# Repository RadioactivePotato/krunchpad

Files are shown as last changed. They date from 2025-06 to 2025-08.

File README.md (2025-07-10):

# krunchpad
A macropad powered by RP2040

# Images

| Schematic | PCB | 3D Preview | Case |
|:---:|:---:|:----:|:----:|
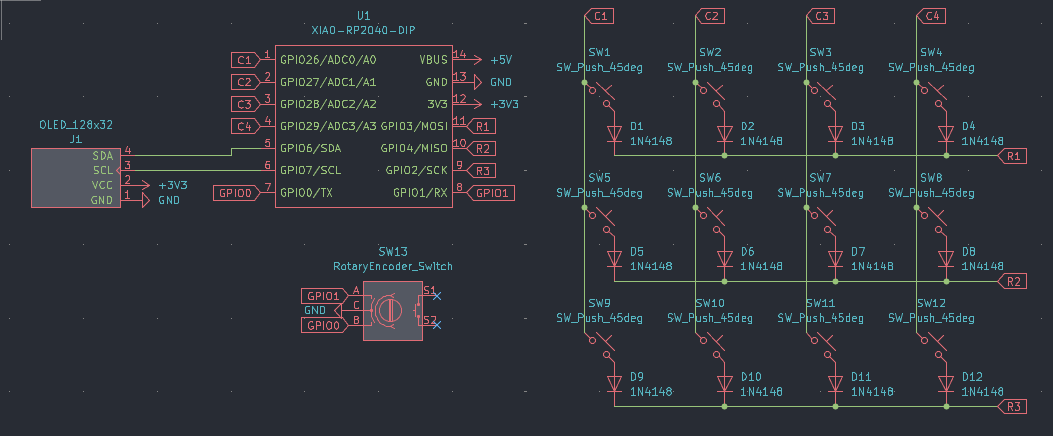
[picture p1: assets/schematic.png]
Schematic
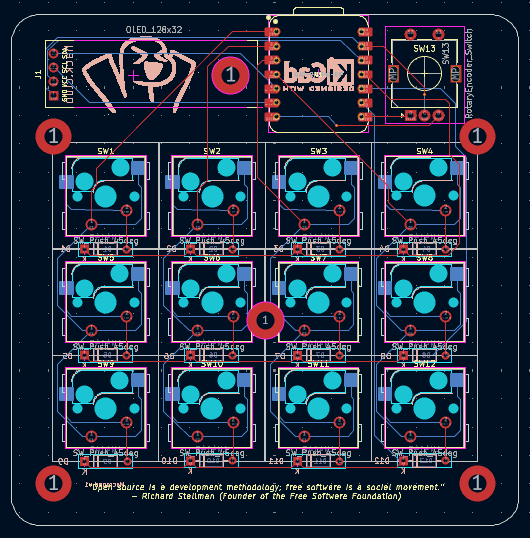
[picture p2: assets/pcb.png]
PCB
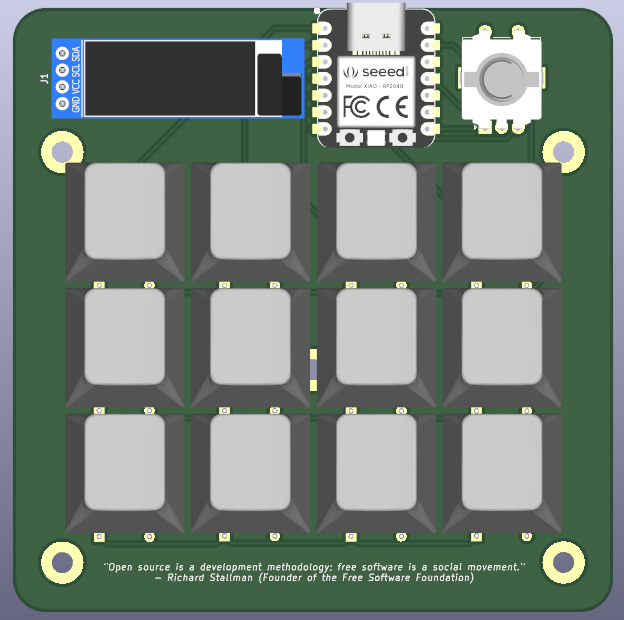
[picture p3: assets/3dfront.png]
3D-Front
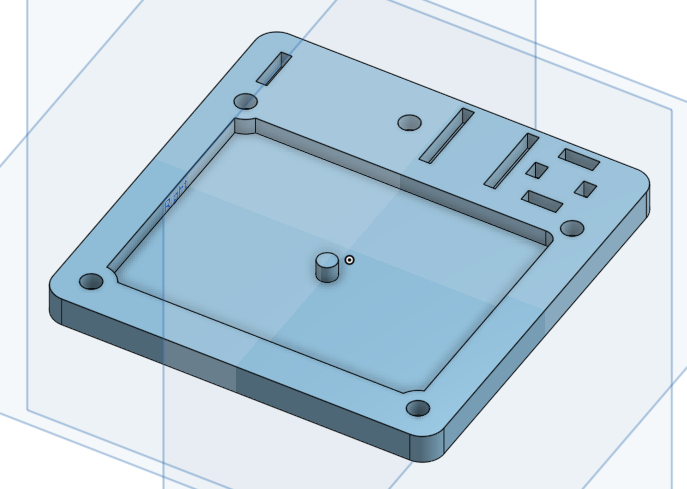
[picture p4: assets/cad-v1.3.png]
Baseplate
|  |  |  |  |
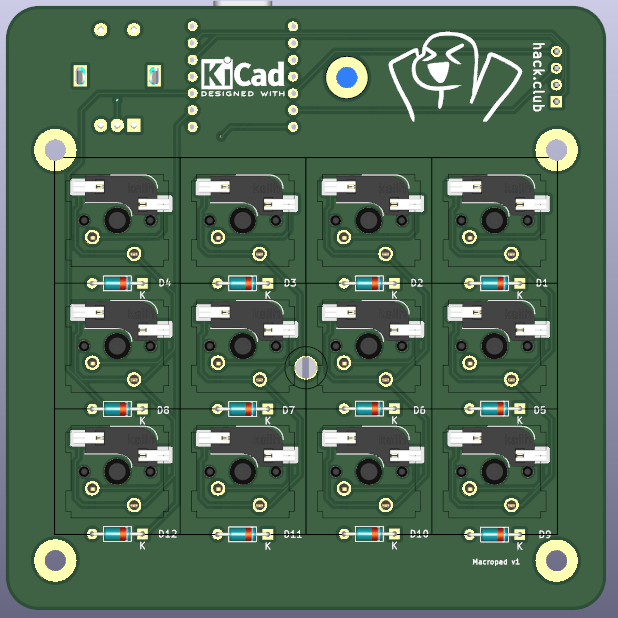
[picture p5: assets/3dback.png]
3D-Back
| | |  | |

# Case

| Layout | Layout | Layout |
| :----: | :----: | :----: |
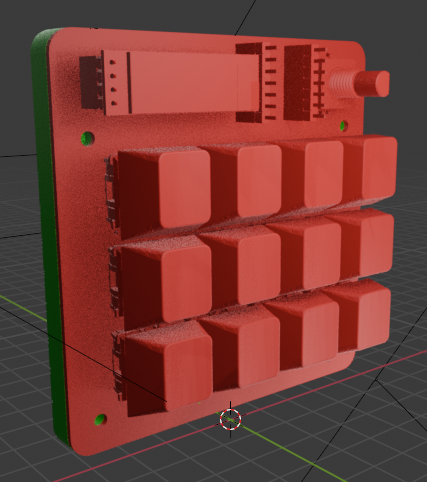
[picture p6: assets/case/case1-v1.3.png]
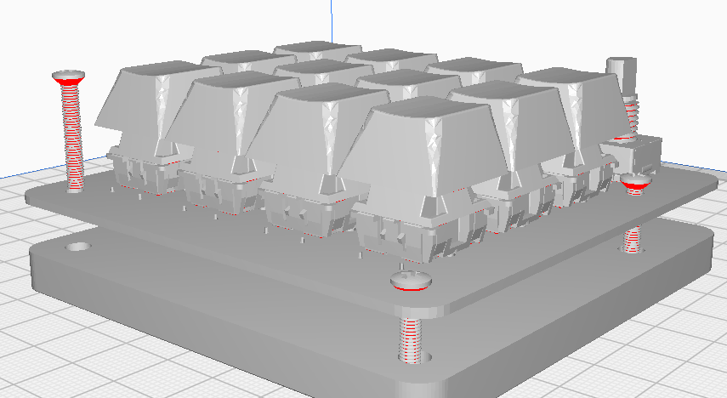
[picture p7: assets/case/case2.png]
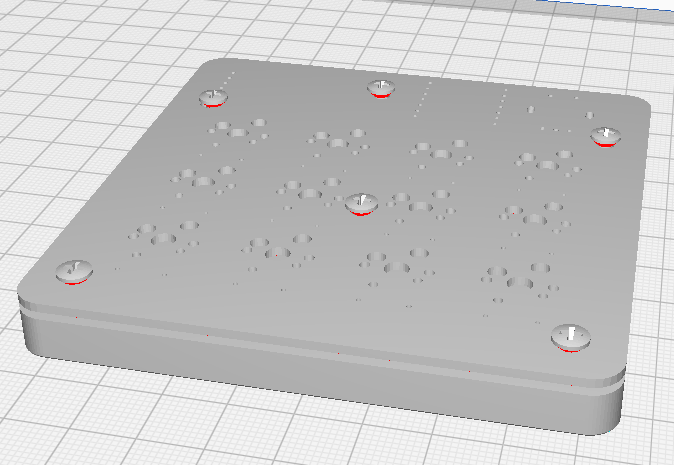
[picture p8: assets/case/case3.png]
|  |  |  |

# BOM
| Qty  | Item | Notes | Cost (USD)| URL |
|---|---|---|---|---|
| 1 | Seeed Studio XIAO RP2040 | Microcontroller | $4.68 | [URL](https://www.digikey.co.uk/en/products/detail/seeed-technology-co-ltd/102010428/14672129) |
| 12 | THT 1N4148 Diode (DO-35 Footprint) | For switch matrix | $0.41 | [URL](https://www.digikey.co.uk/en/products/detail/diotec-semiconductor/1N4148/13164514) |
| 12 | MX-Style Switches | Mechanical key switches | | |
| 1 | EC11 Rotary Encoder | Volume control | $1.87 | [URL](https://www.digikey.co.uk/en/products/detail/bourns-inc/PEC11R-4215K-S0012/4499639) |
| 1 | 0.91" OLED Display | | | |
| 12 | Keycaps | | | |
| 5 | M3x5mmx4mm Heatset Inserts (W*H) | For mounting | | |
| 6 | M3 Screws (5.6mm Max) | For case assembly | | |
|------|------------------------------------|---------------------------|-----------|---------|
| 1 | Soldering Iron + Solder | Tools | | |
| 1 | 3D Printed Case | Custom enclosure | | |
| 1 | PCB | | | |
|------|------------------------------------|---------------------------|-----------|---------|
| 2 | 2.54mm 4POS Header (Included) | OLED Mounting | | |
| 2 | 2.54mm 4POS Socket | OLED Mounting | $0.25 | [URL](https://www.digikey.co.uk/en/products/detail/adam-tech/RS1-04-G/9829303) |
| 2 | 2.54mm 7POS Header | MCU Mounting | $0.20 | [URL](https://www.digikey.co.uk/en/products/detail/adam-tech/PH1-07-UA/9830505) |
| 2 | 2.54mm 7POS Socket | MCU Mounting | $0.84 | [URL](https://www.digikey.co.uk/en/products/detail/adam-tech/RS1-07-G/9832045) |
| 12 | Kailh MX Hotswap Socket (Optional) | Hotswapping for switches  | $4.95 | [URL](https://www.digikey.co.uk/en/products/detail/adafruit-industries-llc/4958/13997772) |
|------|------------------------------------|---------------------------|-----------|---------|

# Cases
- V1

Simple base plate with slots for heatset inserts

- V1.1

Added holes for the PCB to sit flush with the case where there are THT componants

- V1.2

Added a support knob to support the PCB in the center of the case

- V1.3

Added slots for the socket for the MCU

Removed the curved corners for the holes

A badge of a Cerberus and a raccoon laughing together, with the text "HIGHWAY" and "HACK CLUB" beside them.

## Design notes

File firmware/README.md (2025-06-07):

### Features

#### 3×4 Key Matrix

* 12 customizable keys in 3 rows and 4 columns.
* Default keymap sends letters A–L.

#### Rotary Encoder

* EC11 rotary encoder connected to GPIO0 and GPIO1.
* Turns:

  * Clockwise > Volume Up
  * Counterclockwise > Volume Down

#### OLED Display

* Displays `"Hello World"` centered vertically on boot.
* OLED dims after 10 seconds of inactivity, turns off after 20 minutes (1200 seconds).

---

### Pins

| Function | GPIO Pins |
| --- | --- |
| Matrix Rows | GP3, GP4, GP2 |
| Matrix Columns | GP26, GP27, GP28, GP29 |
| Encoder A/B | GP1, GP0 |

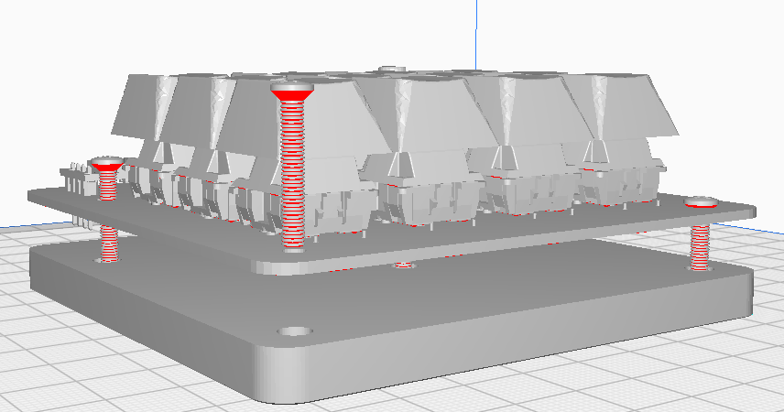
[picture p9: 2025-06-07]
assets/case/case1.png

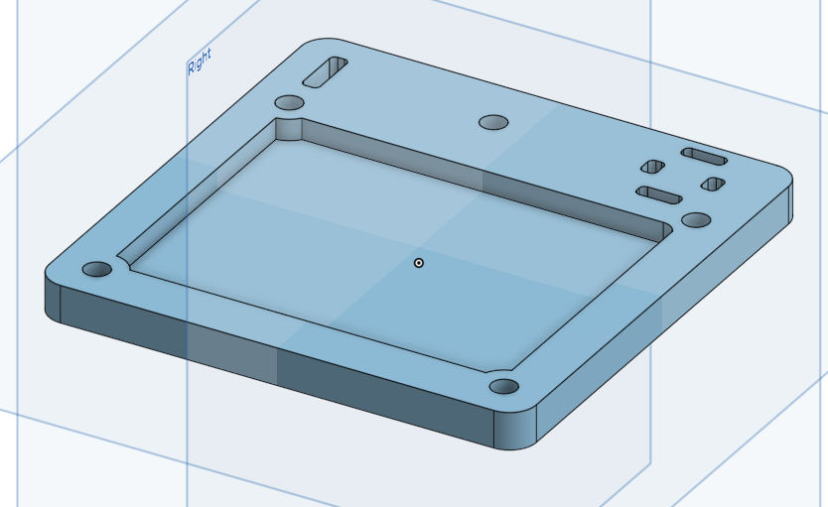
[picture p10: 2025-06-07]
assets/cad-v1.1.png

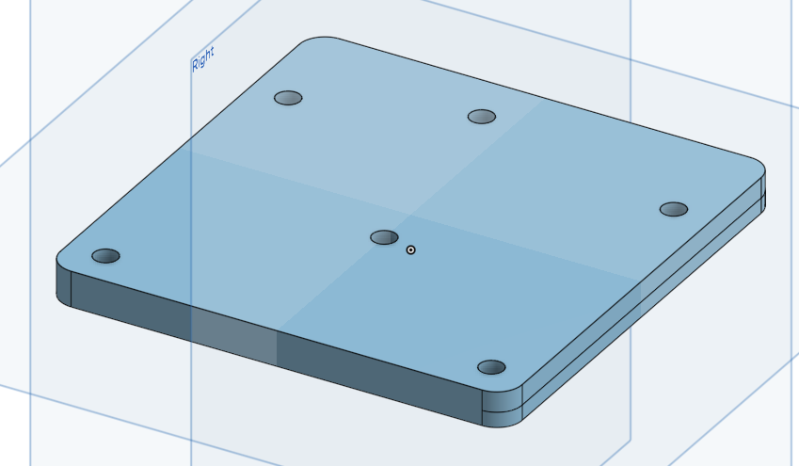
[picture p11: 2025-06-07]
assets/cad-v1.png

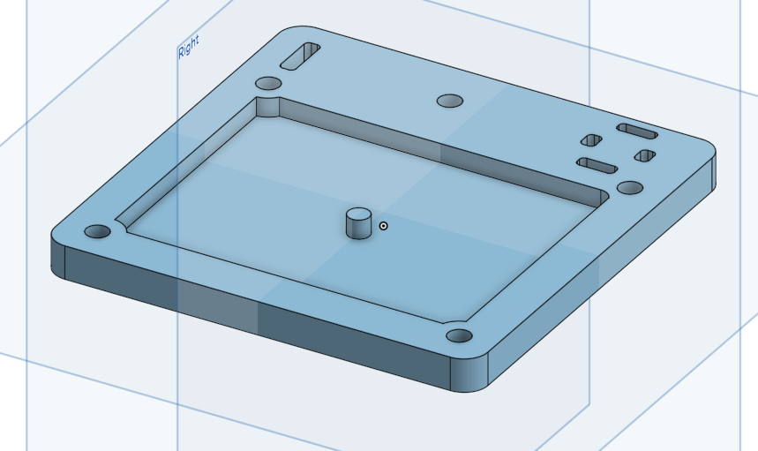
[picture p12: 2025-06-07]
assets/cad-v1.2.png

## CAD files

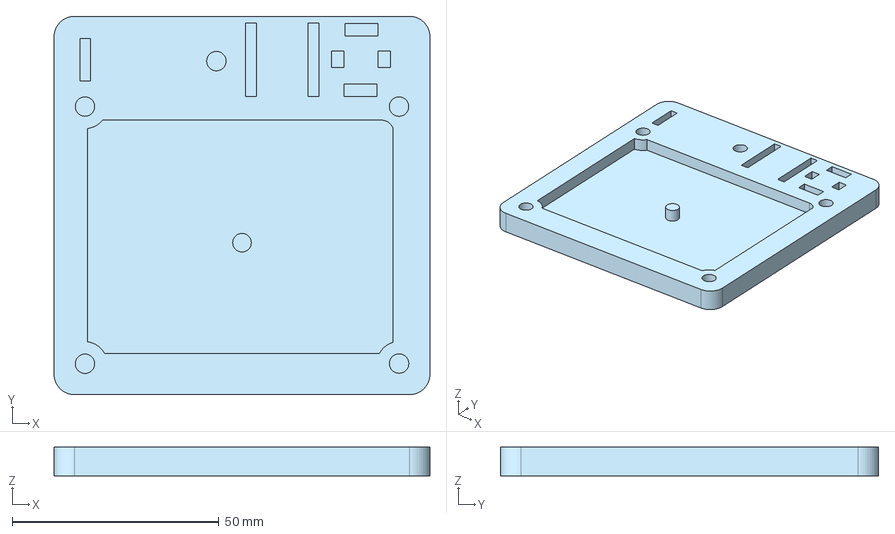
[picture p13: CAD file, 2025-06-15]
cad/v1.3-krunchpad-baseplate.step
91.0 x 91.6 x 7.00 mm

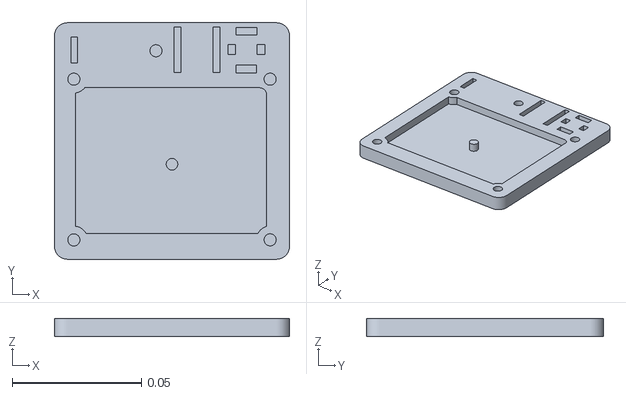
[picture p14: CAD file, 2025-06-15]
production/v1.3-krunchpad-baseplate.stl
0.091 x 0.0916 x 0.007

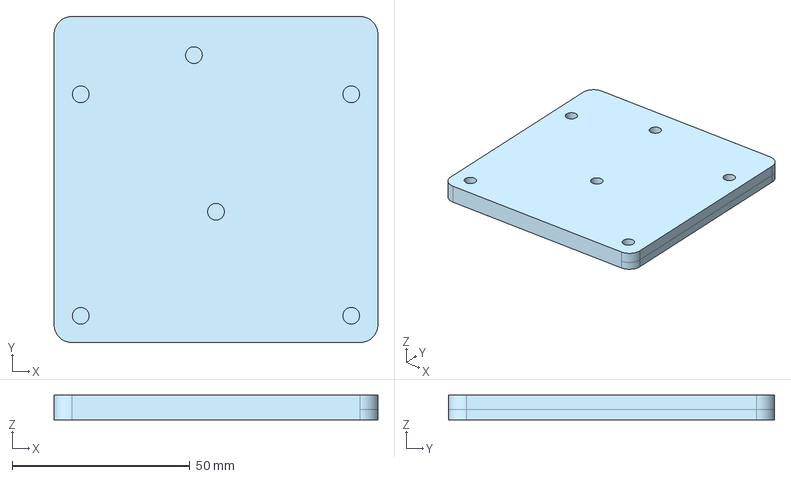
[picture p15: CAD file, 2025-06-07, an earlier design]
cad/v1-krunchpad-baseplate.step
91.0 x 91.6 x 7.00 mm

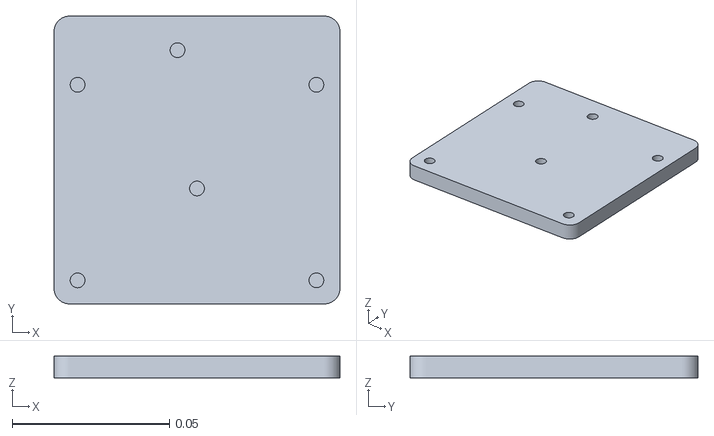
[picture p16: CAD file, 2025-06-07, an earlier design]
production/v1-krunchpad-baseplate.stl
0.091 x 0.0916 x 0.007

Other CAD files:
production/v1.2-krunch-baseplate.stl
cad/v1.1krunchpad-baseplate.step
cad/v1.2-krunchpad-baseplate.step
production/v1.1-krunchpad-baseplate.stl

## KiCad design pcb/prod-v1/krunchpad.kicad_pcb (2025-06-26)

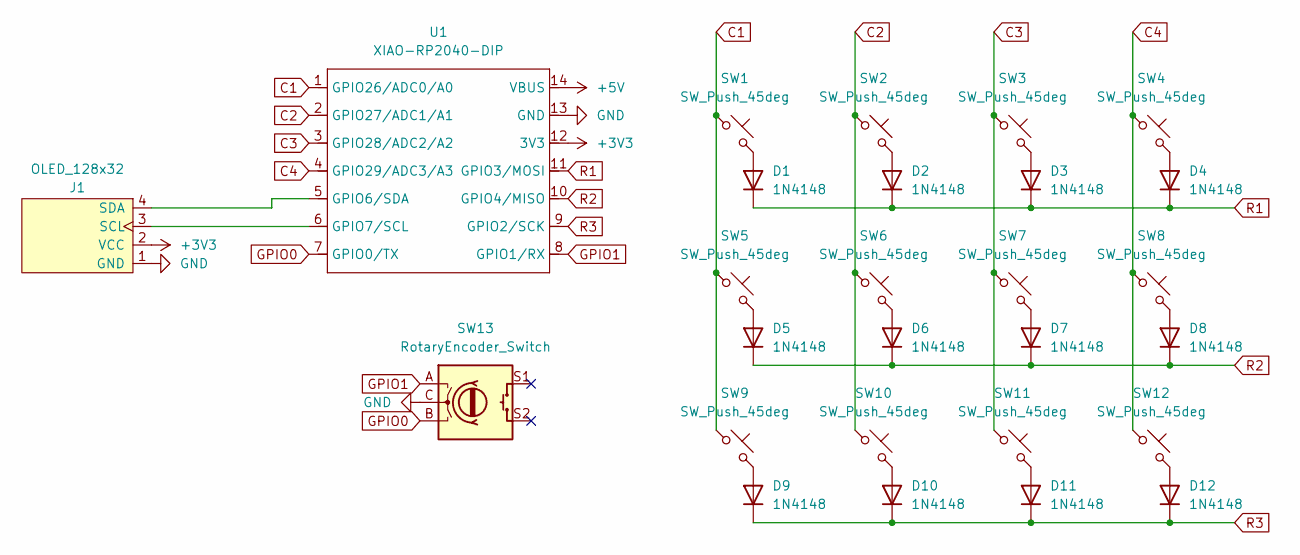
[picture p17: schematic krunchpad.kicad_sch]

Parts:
D1, D2, D3, D4, D5, D6, D7, D8, D9, D10, D11, D12: 1N4148; D_DO-35_SOD27_P7.62mm_Horizontal
J1: OLED_128x32; SSD1306-0.91-OLED-4pin-128x32
SW1, SW2, SW3, SW4, SW5, SW6, SW7, SW8, SW9, SW10, SW11, SW12: SW_Push_45deg; dual-hotswap_MX
SW13: RotaryEncoder_Switch; RotaryEncoder_Alps_EC11E-Switch_Vertical_H20mm
U1: XIAO-RP2040-DIP

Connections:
+3V3: J1.2 (VCC), U1.12 (3V3)
+5V: U1.14 (VBUS)
C1: SW1.1, SW5.1, SW9.1, U1.1 (GPIO26/ADC0/A0)
C2: SW2.1, SW6.1, SW10.1, U1.2 (GPIO27/ADC1/A1)
C3: SW3.1, SW7.1, SW11.1, U1.3 (GPIO28/ADC2/A2)
C4: SW4.1, SW8.1, SW12.1, U1.4 (GPIO29/ADC3/A3)
GND: J1.1 (GND), SW13.C, U1.13 (GND)
GPIO0: SW13.B, U1.7 (GPIO0/TX)
GPIO1: SW13.A, U1.8 (GPIO1/RX)
unnamed: D1.2 (A), SW1.2
unnamed: D2.2 (A), SW2.2
unnamed: D3.2 (A), SW3.2
unnamed: D4.2 (A), SW4.2
unnamed: D5.2 (A), SW5.2
unnamed: D6.2 (A), SW6.2
unnamed: D7.2 (A), SW7.2
unnamed: D8.2 (A), SW8.2
unnamed: D9.2 (A), SW9.2
unnamed: D10.2 (A), SW10.2
unnamed: D11.2 (A), SW11.2
unnamed: D12.2 (A), SW12.2
unnamed: J1.3 (SCL), U1.6 (GPIO7/SCL)
unnamed: J1.4 (SDA), U1.5 (GPIO6/SDA)
R1: D1.1 (K), D2.1 (K), D3.1 (K), D4.1 (K), U1.11 (GPIO3/MOSI)
R2: D5.1 (K), D6.1 (K), D7.1 (K), D8.1 (K), U1.10 (GPIO4/MISO)
R3: D9.1 (K), D10.1 (K), D11.1 (K), D12.1 (K), U1.9 (GPIO2/SCK)

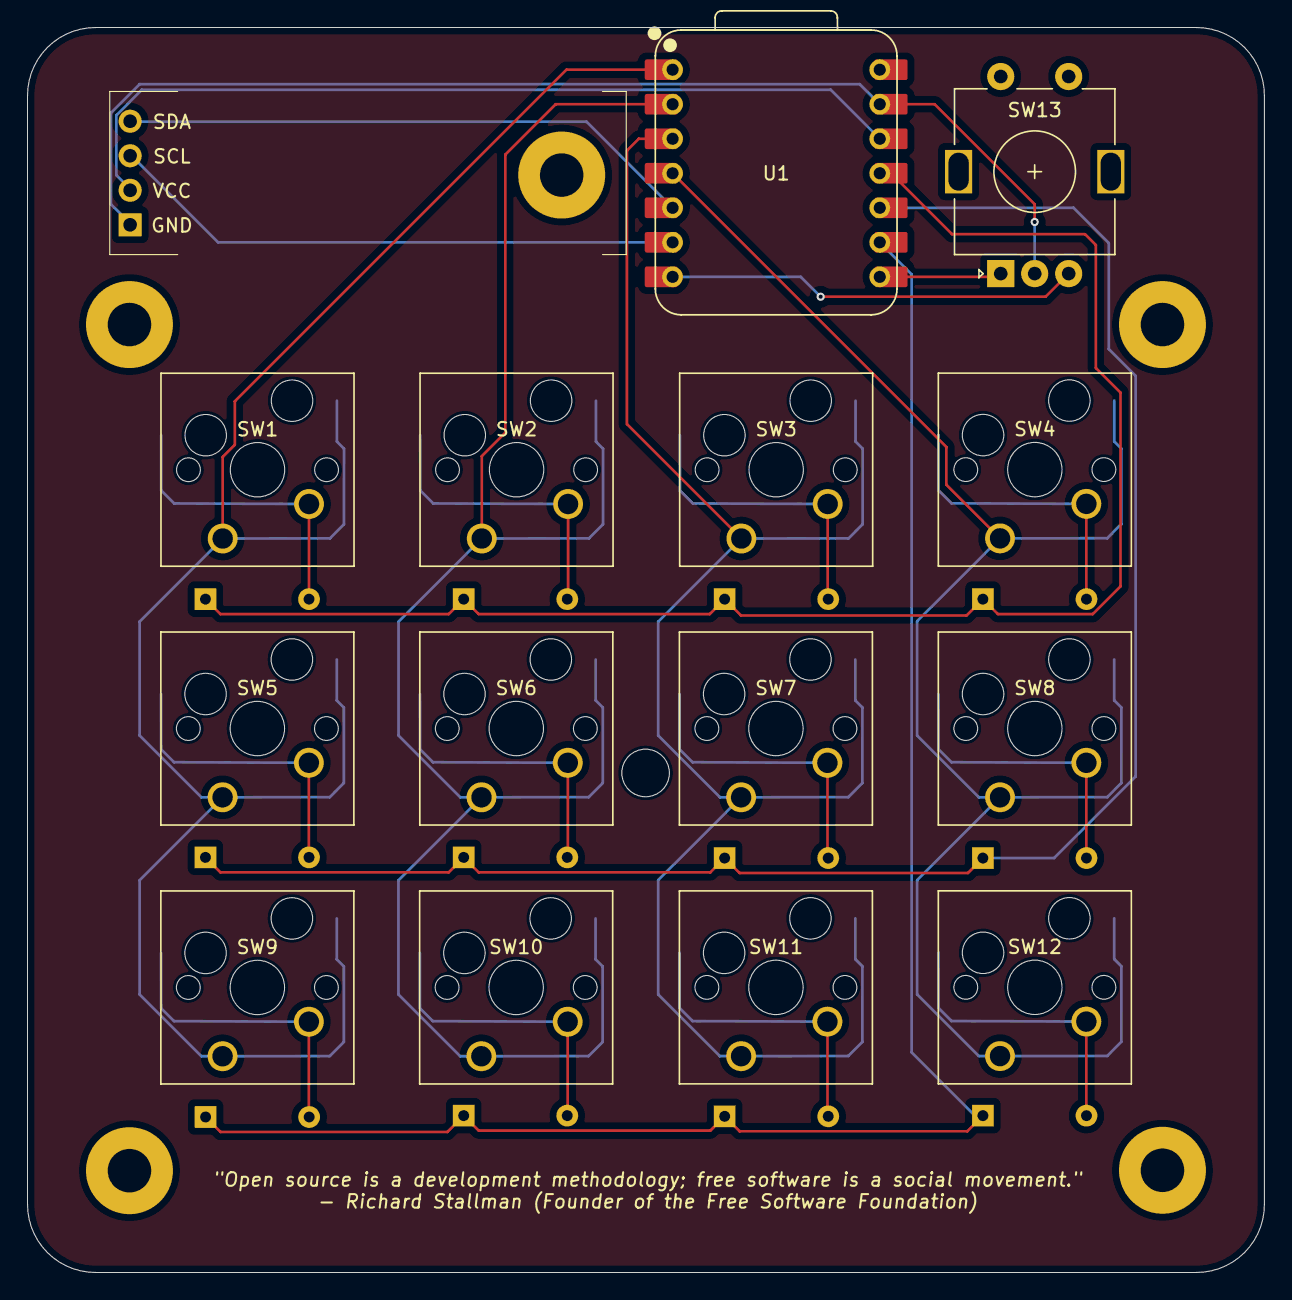
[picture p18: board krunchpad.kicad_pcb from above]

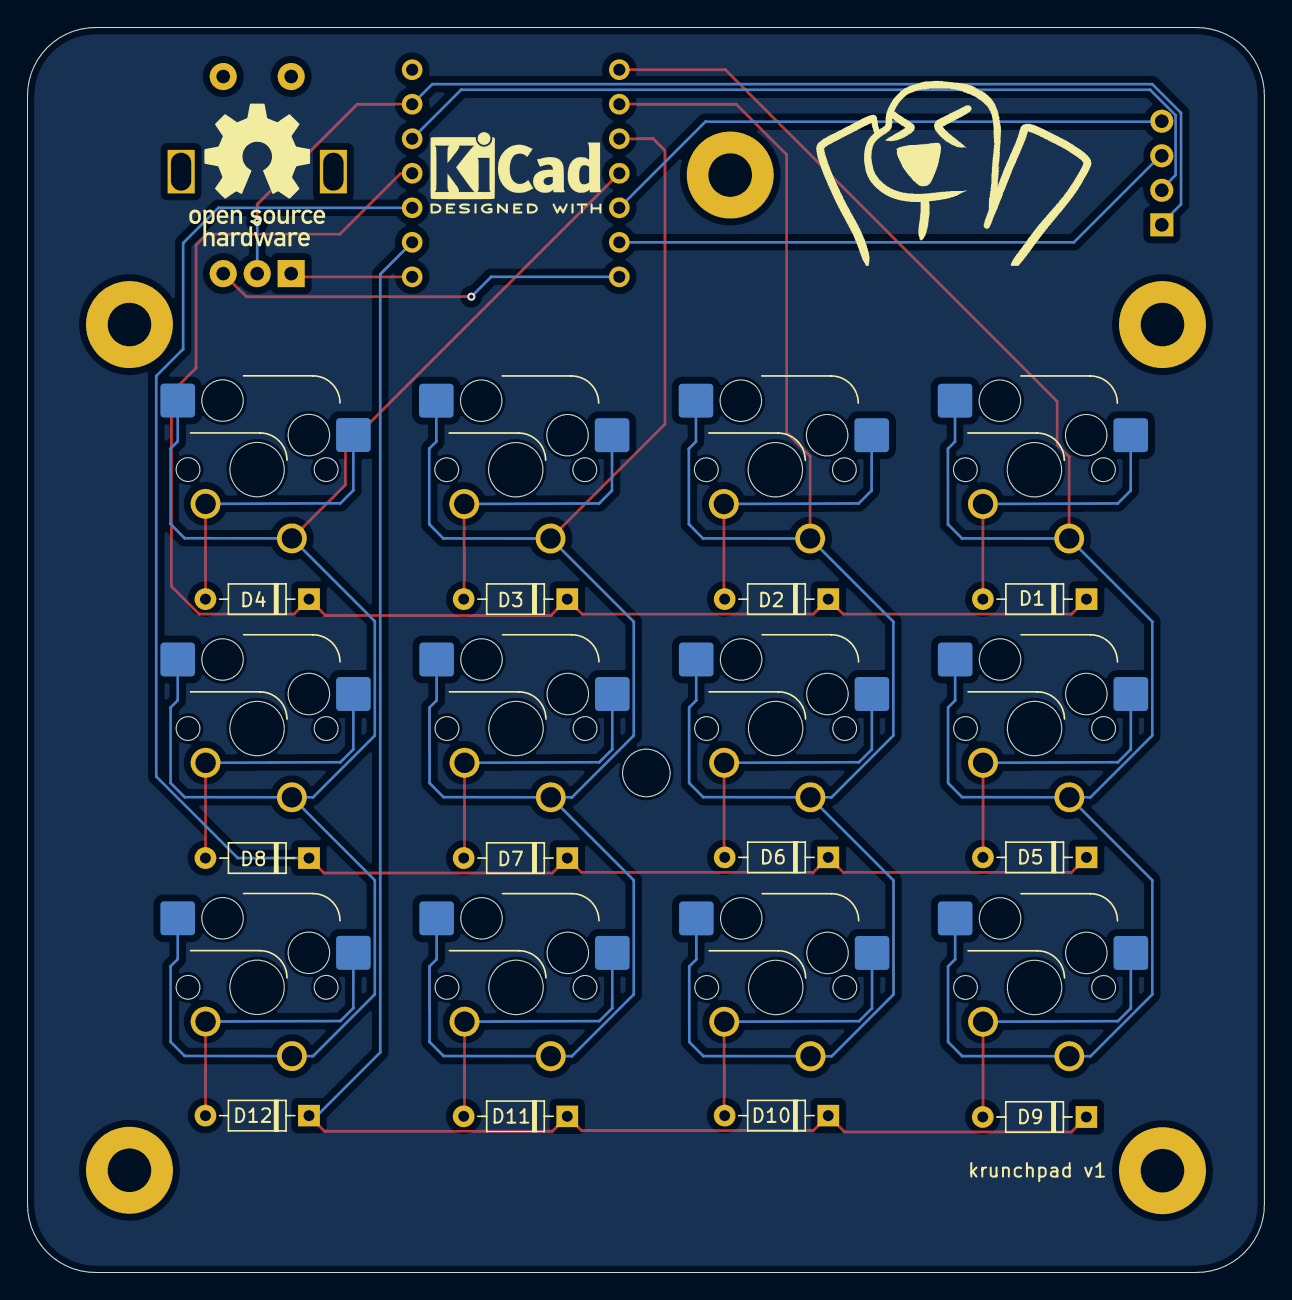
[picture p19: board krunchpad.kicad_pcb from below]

Board: 2 copper layers, 91.0 x 91.6 mm, 28 parts (13 on the bottom side), 25 nets.

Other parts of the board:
logo1: KiCad-Logo2_5mm_SilkScreen

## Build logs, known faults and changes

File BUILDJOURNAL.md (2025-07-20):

# krunchpad Build Journal

# Introduction

I will be using the KSGER PD210 Soldering iron, it supposedly can go up to 70W but I'll only be able to get up to 27W since I'm using 9V 3A power supply.

The tip I will be using is a small knife tip that came with the soldering iron.



# Heatset Inserts

This is pretty easy to install, the bottom of the insert keeps it in the hole while I push it in with my soldering iron around 330c



# OLED Display and MCU

After installing the heatset inserts, I began soldering the OLED display, some of the pins have a bit too much solder but it'll work



And then I moved onto the MCU, again, some pins have a bit too much solder, but it's fine

| Left | Right |
|---|---|
|  |  |

I think it looks pretty good!

# Rotary Encoder

The rotary encoder is a bit harder to solder mainly because the side pins (the wide ones) are directly connected to the housing of the encoder, which is all metal, and it sucks away all the heat from the soldering iron very quickly, but I turned the iron up to around 400c and it works fine at the temperature.

One nice thing about the rotary encoder is that it holds itself in place when soldering, so I don't need to use tape to hold it to the PCB.

| Top | Bottom |
|-----|---|
|  |  |

# Diodes

Diodes are pretty easy to solder, I just have to bend the pins and slot them into the holes, then open it back up so it stays in place, then I can solder each one.

Once I'm done with each row, I cut the excessive leads off and it looks great

[Forgot to take a photo]





After I was finished, I realised it'd look better if the diodes were on the top side of the pcb lol

# Switches

This is also pretty easy to solder, firstly, I install the keycaps, and then carefully flip the macropad upside down (so the keycaps is on the desk)

And then I solder each switch one by one.



Unfortunarly I can't clean off the flux since they aren't water soluble and I don't have IPA, so they're staying on the board for now (pretty sure it's no clean as well)

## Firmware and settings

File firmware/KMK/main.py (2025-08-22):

import board
from kmk.kmk_keyboard import KMKKeyboard
from kmk.scanners.keypad import MatrixScanner
from kmk.keys import KC
from kmk.modules.encoder import EncoderHandler
from kmk.scanners import DiodeOrientation
from kmk.extensions.display import Display, TextEntry
from kmk.extensions.display.ssd1306 import SSD1306
from kmk.extensions.RGB import RGB, AnimationModes
from kmk.extensions.LED import LED

keyboard = KMKKeyboard()

# matrix
keyboard.row_pins = (board.D10, board.D9, board.D8)
keyboard.col_pins = (board.D0, board.D1, board.D2, board.D3)
keyboard.diode_orientation = DiodeOrientation.COL2ROW

keyboard.keymap = [
    [
        KC.TAB, KC.Q, KC.W, KC.E,
        KC.LSHIFT, KC.A, KC.S, KC.D,
        KC.LCTRL, KC.F3, KC.F5, KC.SPACE,
    ]
]

# volume knob
encoder = EncoderHandler()
encoder.pins = ((board.D7, board.D6),)
encoder.map = [((KC.VOLU, KC.VOLD))]  # cw = vol up, ccw = vol down
keyboard.modules.append(encoder)

# 128x32 OLED display

keyboard.SCL = board.D5
keyboard.SDA = board.D4

display = Display(
    display=SSD1306(sda=board.D4, scl=board.D5),
    entries=[
        TextEntry(text="""
hello
world
        """),
    ],
    height=32,
)
keyboard.extensions.append(display)

# MCU neopixel

mcuneopixel = RGB(
    pixel_pin=board.NEOPIXEL,
    num_pixels=1,
    val_limit=100,
    val_default=25,
    animation_mode=AnimationModes.RAINBOW,
)
keyboard.extensions.append(mcuneopixel)

if __name__ == '__main__':
    keyboard.go()

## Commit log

2025-06-07 case layout
2025-06-07 updated case model and image
    [v1-krunchpad-baseplate.step, v1-krunchpad-baseplate.stl, v1.1-krunchpad-baseplate.stl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]
2025-06-07 changed case image
2025-06-07 readme case image
2025-06-07 case v1.2
    [v1.2-krunch-baseplate.stl, v1.2-krunchpad-baseplate.step]
2025-06-07 case v1.2 image
2025-06-09 Update BOM
2025-06-12 deleted old files
    [krunchpad.kicad_pcb, krunchpad.kicad_sch]
2025-06-12 added silkscreen stuff, and copper fill
    [krunchpad.kicad_pcb, krunchpad.kicad_sch]
2025-06-15 case v1.3
    [v1.3-krunchpad-baseplate.step, v1.3-krunchpad-baseplate.stl]
2025-06-15 readme case v1.3 image
2025-06-16 Updated bill of materials for OLED and MCU mounting
2025-06-21 updated bom values
2025-06-21 added urls to bom
2025-06-26 removed old pcb designed files to be replaced with new ones
    [krunchpad.kicad_pcb, krunchpad.kicad_sch]
2025-06-26 final v1 files
    [krunchpad.kicad_pcb, krunchpad.kicad_sch]
2025-07-23 updated code to make oled work, +non functional neopixel, fixed pin names
    [main.py]
